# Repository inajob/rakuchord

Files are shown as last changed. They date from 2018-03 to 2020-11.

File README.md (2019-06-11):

# RakuChord - らくこーど

楽にそれっぽい演奏ができる楽器です。

紹介ページ: https://inajob.github.io/rakuchord/

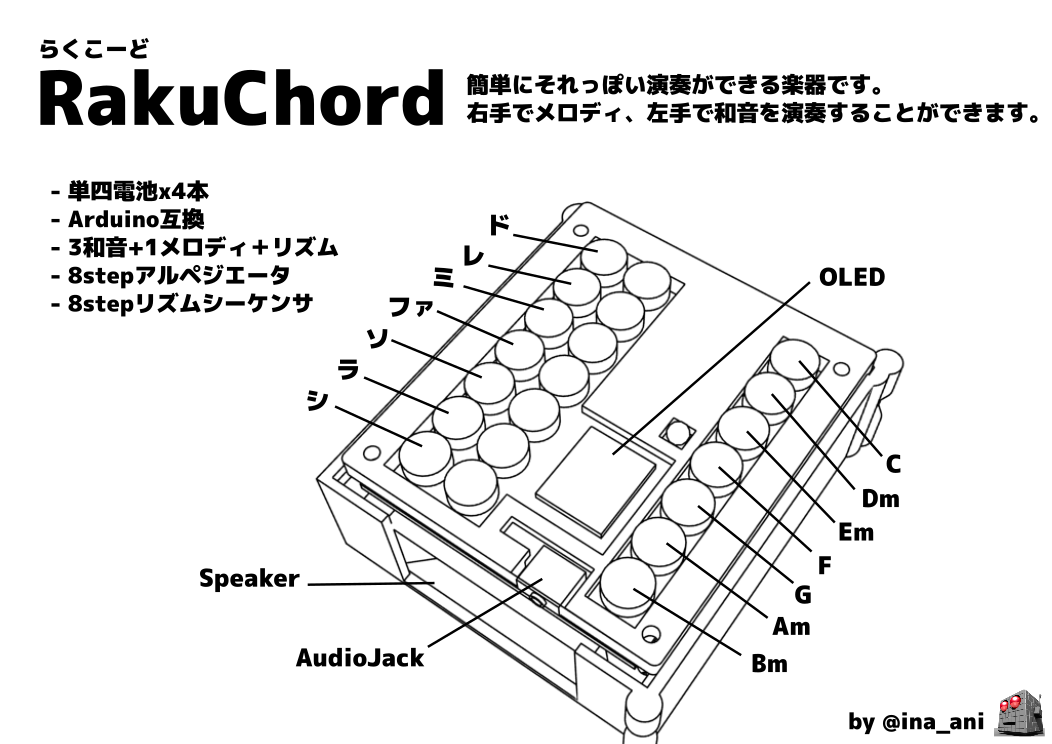
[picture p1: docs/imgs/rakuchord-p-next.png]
RakuChord


# ディレクトリ構成

- docs
  - github pages用ページ
- firmware
  - 本体firmware
- model
  - 筐体データ
- circuit
  - 回路図

# ファームウェアの更新

ビルドには[Platformio](https://platformio.org/)を利用しています。
このリポジトリをCloneしたのちに下記コマンドでファームウェアを更新できます。

```
$ cd firmware
$ platformio run
```

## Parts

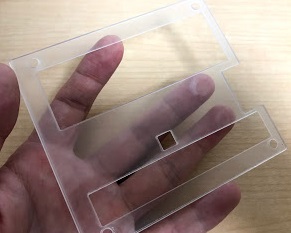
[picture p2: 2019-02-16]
docs/imgs/parts-next/top-panel.jpg

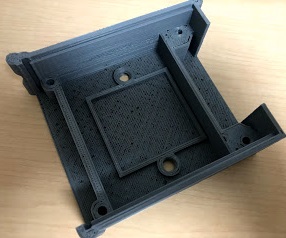
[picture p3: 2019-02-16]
docs/imgs/parts-next/bottom.jpg

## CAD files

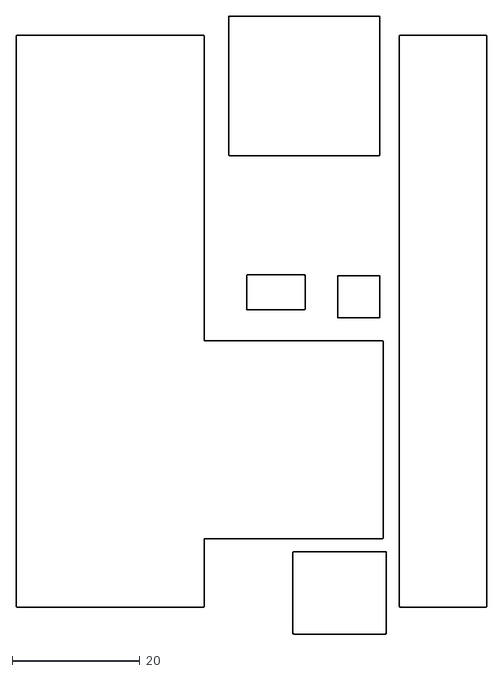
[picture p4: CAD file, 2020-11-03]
model/dxf-1-4/rakuchord-draft-Dwgs_User.dxf
73.7 x 96.7

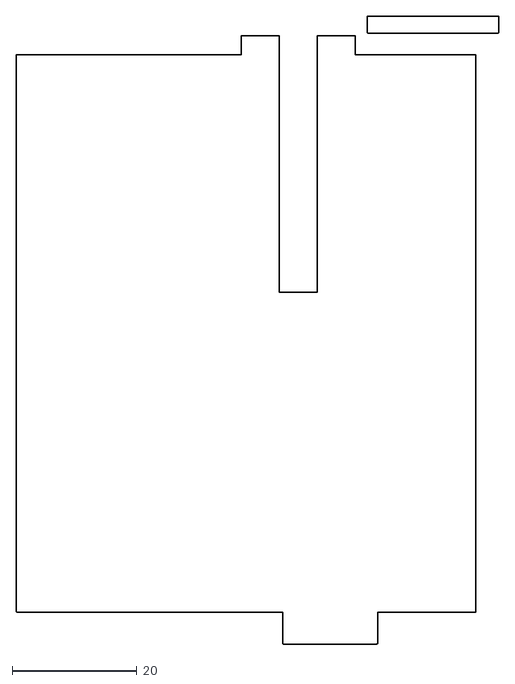
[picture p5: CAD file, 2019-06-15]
model/dxf/rakuchord-draft-Eco1.User.dxf
77.3 x 100.7

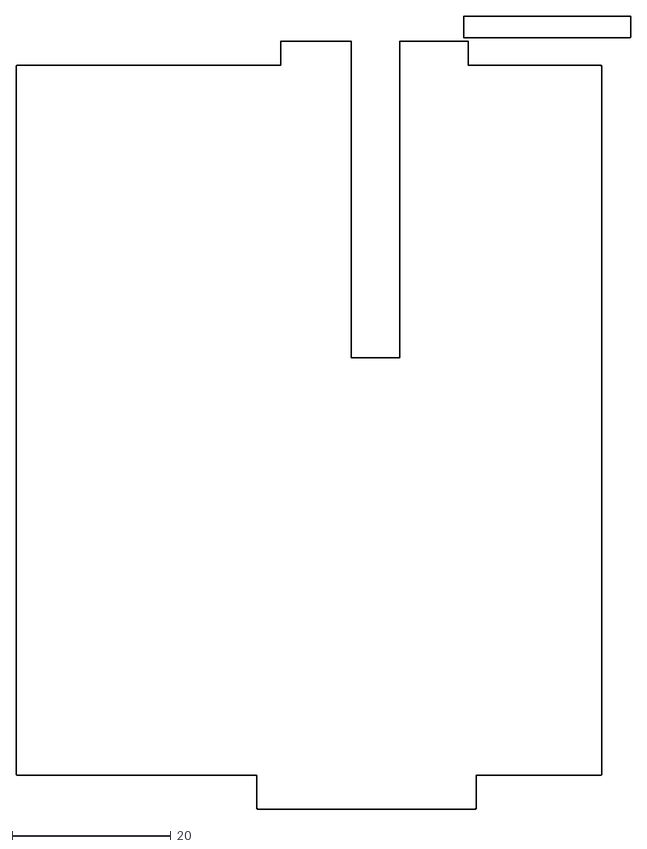
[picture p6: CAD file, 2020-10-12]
model/dxf-1-4/rakuchord-draft-Eco1_User.dxf
77.3 x 99.8

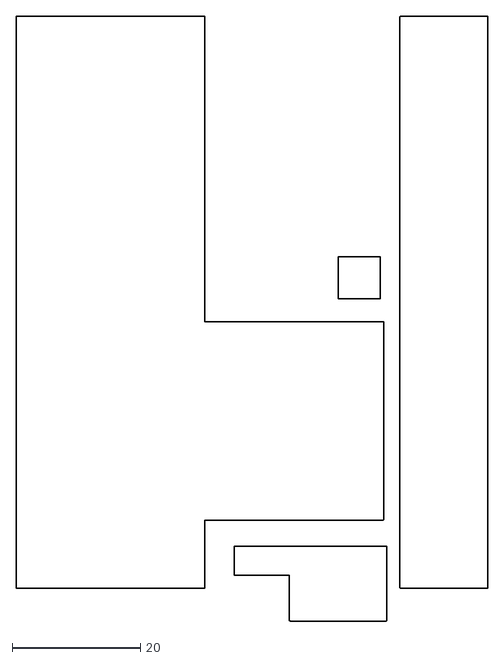
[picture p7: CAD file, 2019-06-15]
model/dxf/rakuchord-draft-Dwgs.User.dxf
73.7 x 94.5

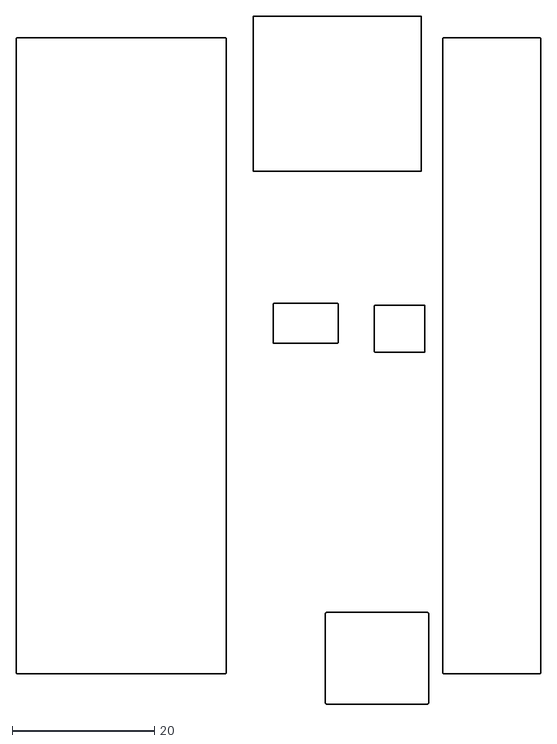
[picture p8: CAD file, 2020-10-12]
model/dxf-1-4/rakuchord-draft-Margin.dxf
73.7 x 96.7

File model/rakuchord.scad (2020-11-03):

include <polyScrewThread_r1.scad>;

//linear_extrude(height = 5, center = true, convexity = 10)
$fn=50;

module screw_hole(){
    translate([92/2 - 5, 92/2-2 + 1,0]) screw_hole_model();
    translate([92/2 - 5, -92/2 + 3,0]) screw_hole_model();

    translate([-92/2 + 5, 92/2-2 + 1,0]) screw_hole_model();
    translate([-92/2 + 5, -92/2 + 3,0]) screw_hole_model();
}
module screw_hole_model(){
    union(){
        cylinder(h = 5, r1 = 3.5, r2 = 3.5, center = false, $fn=6);    
        translate([0,0,5])
          cylinder(h = 3, r1 = 3.5, r2 = 2.5, center = false);
        translate([0,0,0])
          cylinder(h = 200, r1 = 2.5, r2 = 2.5);
    }
}

module base_board(){
      square([92, 100], center = true);
}

module base_board_space(){
    minkowski()
    {
      // base board
      base_board();
      // margin
      circle(1);
    }
}

module hemi_sphere(r){
    difference(){
      sphere(r);
      translate([0,0,-r])cube([r*2,r*2,r*2],center = true);
    }
}

module upper_case_outer(){
    translate([0,0, 6]) rotate([0,180,0]) linear_extrude(6){
        translate([0,3,0])
          offset(2) offset(-2){
            square([93,100+4], center=true);
          }
    }
}

module upper_hole(){
  //square([73, 90], center = true);
  translate([-136,77,0])
    import(file = "dxf/rakuchord-draft-Eco1_User.dxf");
}
module upper_hole2(){
  translate([-136,77,0])
    import(file = "dxf/rakuchord-draft-Dwgs_User.dxf");
}

module key1_space(){
  translate([12+8,100/2 - 1,1]) square([23,3]); // key1
  translate([-6,100/2 - 5,1]) square([25,3]); // key1
}

module cable_hole(){
  translate([-5,-100/2,1]) square([30,5]);
}

module jack_diff(){
    translate([13.5,-40,0]) rotate([90,0,0]) linear_extrude(height=20){
       translate([0,5,0])square([14+2,14], center = true);
       circle(7);
    }
}

*base_board();

// not maintain: case
*union(){
    difference(){
        upper_case_outer(13);
        translate([0,0,-8])linear_extrude(height=11){
          screw_hole(r=4);
          upper_hole();
          *cable_hole();
          translate([-5,-53,1]) square([30,8]);
        }
    }
}

// no use: upper parts of top
*linear_extrude(height=3) difference(){
    translate([0,0, 0]) rotate([0,180,0]){
        translate([0,3,0])
          offset(2) offset(-2){
            square([93,100+4], center=true);
          }
    }
    translate([92/2 - 5, 92/2-2 + 1,0]) circle(2);
    translate([92/2 - 5, -92/2 + 3,0]) circle(2);
    translate([-92/2 + 5, 92/2-2 + 1,0]) circle(2);
    translate([-92/2 + 5, -92/2 + 3,0]) circle(2);
    upper_hole();
}

// no use: lower parts of top
*translate([0,0,3]) linear_extrude(height=3) difference(){
    translate([0,0, 0]) rotate([0,180,0]){
        translate([0,3,0])
          offset(2) offset(-2){
            square([93,100+4], center=true);
          }
    }

    translate([92/2 - 5, 92/2-2 + 1,0]) circle(2);
    translate([92/2 - 5, -92/2 + 3,0]) circle(2);
    translate([-92/2 + 5, 92/2-2 + 1,0]) circle(2);
    translate([-92/2 + 5, -92/2 + 3,0]) circle(2);

    upper_hole2();
}

// top
*translate([0,0,40]) difference(){
    upper_case_outer();
    translate([0,0,0])linear_extrude(height=3){
      upper_hole();
      *cable_hole();
    }
    translate([0,0,-10])linear_extrude(height=50){
      upper_hole2();
    }
    translate([0,0,-30])
      screw_hole();
    translate([0,0,0]) linear_extrude(height=3){
        //base_board_space();
        *difference(){
            offset(1){
                lower_case_outer();
            }
            offset(0){
                lower_case_inner();
            }
        }
    }
    translate([0,0,2])linear_extrude(height=5){
      *key1_space();
    }
    jack_diff();
    // this makes easier for 3D print
    translate([0,0,5.5]) linear_extrude(height = 0.5){
      translate([20,4,0]) square([10,0.5], center = true);
      
      translate([50,45,0]) square([20,0.5], center = true);
      translate([-50,45,0]) square([20,0.5], center = true);
      translate([50,-43,0]) square([20,0.5], center = true);
      translate([-50,-43,0]) square([20,0.5], center = true);
    }
}

module sub_board(){
      translate([0,100/2 + 2,-15]) rotate([90,0,0]) square([93, 30], center = true);
}

module lower_case_outer(){
    hull(){
      translate([93/2 ,100/2 + 2,0]) circle(5, $fn=50);
      translate([-93/2 ,100/2 + 2,0]) circle(5, $fn=50);
    }
    square([92+1+6, 100+10], center = true);
    hull(){
        translate([93/2 -1 ,-100/2,0]) circle(2, $fn=50);
        translate([-93/2 +1 ,-100/2,0]) circle(2, $fn=50);
    }
}
module lower_case_outer_edge(){
  square([92+1, 105], center = true);
}

module lower_case_inner(){
    square([95 - 6, 105], center = true);
    translate([0,52,0]) square([94, 3], center = true);
    translate([0,50,0]) square([93 - 8, 3], center = true);

    translate([0,55,0]) square([93 - 15+10, 5], center = true);
    translate([0,-50,0]) square([57, 5+10], center = true);
}

*sub_board();

module speaker_hold(){
    linear_extrude(height = 20){
        translate([-94/2 + 12,-50 + 5 + 10/2-5,0]) scale(5) {
            translate([-2,-1,0]) square([1, 3.5]);
            mirror([0,1,0]) polygon([[-1,-2.5],[1,-2.5],[1,0],[0,1],[-1,1]]);
            translate([-2,-2,0]) square([1.5,1]);
        }
        
    }
    linear_extrude(height = 15){
        translate([-94/2 + 12,45.5,0]) scale(5) {
            translate([-2,-1,0]){
                square([1, 2]);
                
            }
            translate([-1,0,0]){
                circle(1, $fn=50);
            }
        }
        translate([0,40,0])
          square([49,5]);
    }
}


thread = "none"; //modeled


*translate([0,0,-34]){
    difference(){
        union(){
            linear_extrude(height = 36){
                difference(){
                  lower_case_outer();
                  lower_case_inner();
                }
            }
            difference(){
                union(){
                    linear_extrude(height = 2){
                        lower_case_outer();
                    }
                    linear_extrude(height = 5) translate([33,0,0]) circle(7);
                    linear_extrude(height = 5) translate([-33,0,0]) circle(7);
                }
                hg = 8;  // height
                sth = 4; // step height
                clf = 55; // degrees
                cod = 10; // outer diameter
                crs = 1; // resolution

                //translate([33, 0, 20]) hole_threaded(name="M10", thread = thread);
                //translate([-33, 0, 20]) hole_threaded(name="M10", thread = thread);
                translate([33, 0, 0]) screw_thread(cod,sth,clf,8,crs,-2);
                translate([-33, 0, 0]) screw_thread(cod,sth,clf,8,crs,-2);;
                screw_hole();
            }
            linear_extrude(height = 5){
                difference(){
                    square([50+2+4, 53+2+4], center = true);
                    square([50+1, 53+1], center = true);
                }
            }
            speaker_hold();
            mirror([-1,0,0]) speaker_hold();
            linear_extrude(height=20)translate([0,-32,0])square([96,3],center=true);
            translate([46+2,-51-5,0]){
                cylinder(h = 11, r1 = 4, r2 = 4, $fn = 40);
                translate([0,0,11])cylinder(h = 5, r1 = 4, r2 = 2, $fn = 40);
                
                translate([0,0,16])cylinder(h = 4, r1 = 2, r2 = 2, $fn = 40);
                
                translate([0,0,20])cylinder(h = 5, r1 = 2, r2 = 4, $fn = 40);
                translate([0,0,20 + 5])cylinder(h = 11, r1 = 4, r2 = 4, $fn = 40);
            }
            translate([49,57,0]){
                cylinder(h = 11, r1 = 4, r2 = 4, $fn = 40);
                translate([0,0,11])cylinder(h = 5, r1 = 4, r2 = 2, $fn = 40);
                
                translate([0,0,16])cylinder(h = 4, r1 = 2, r2 = 2, $fn = 40);
                
                translate([0,0,20])cylinder(h = 5, r1 = 2, r2 = 4, $fn = 40);
                translate([0,0,20 + 5])cylinder(h = 11, r1 = 4, r2 = 4, $fn = 40);
            }
        }
        translate([0,0,33]){
            linear_extrude(height = 5){
                lower_case_outer_edge();
            }
        }
        screw_hole();
        // this makes easier for 3D print
        linear_extrude(height = 0.5){
          translate([50,0,0]) square([20,0.5], center = true);
          translate([-50,0,0]) square([20,0.5], center = true);
          translate([50,45,0]) square([20,0.5], center = true);
          translate([-50,45,0]) square([20,0.5], center = true);
          translate([50,-43,0]) square([20,0.5], center = true);
          translate([-50,-43,0]) square([20,0.5], center = true);
        }

    }
}
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

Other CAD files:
model/polyScrewThread_r1.scad

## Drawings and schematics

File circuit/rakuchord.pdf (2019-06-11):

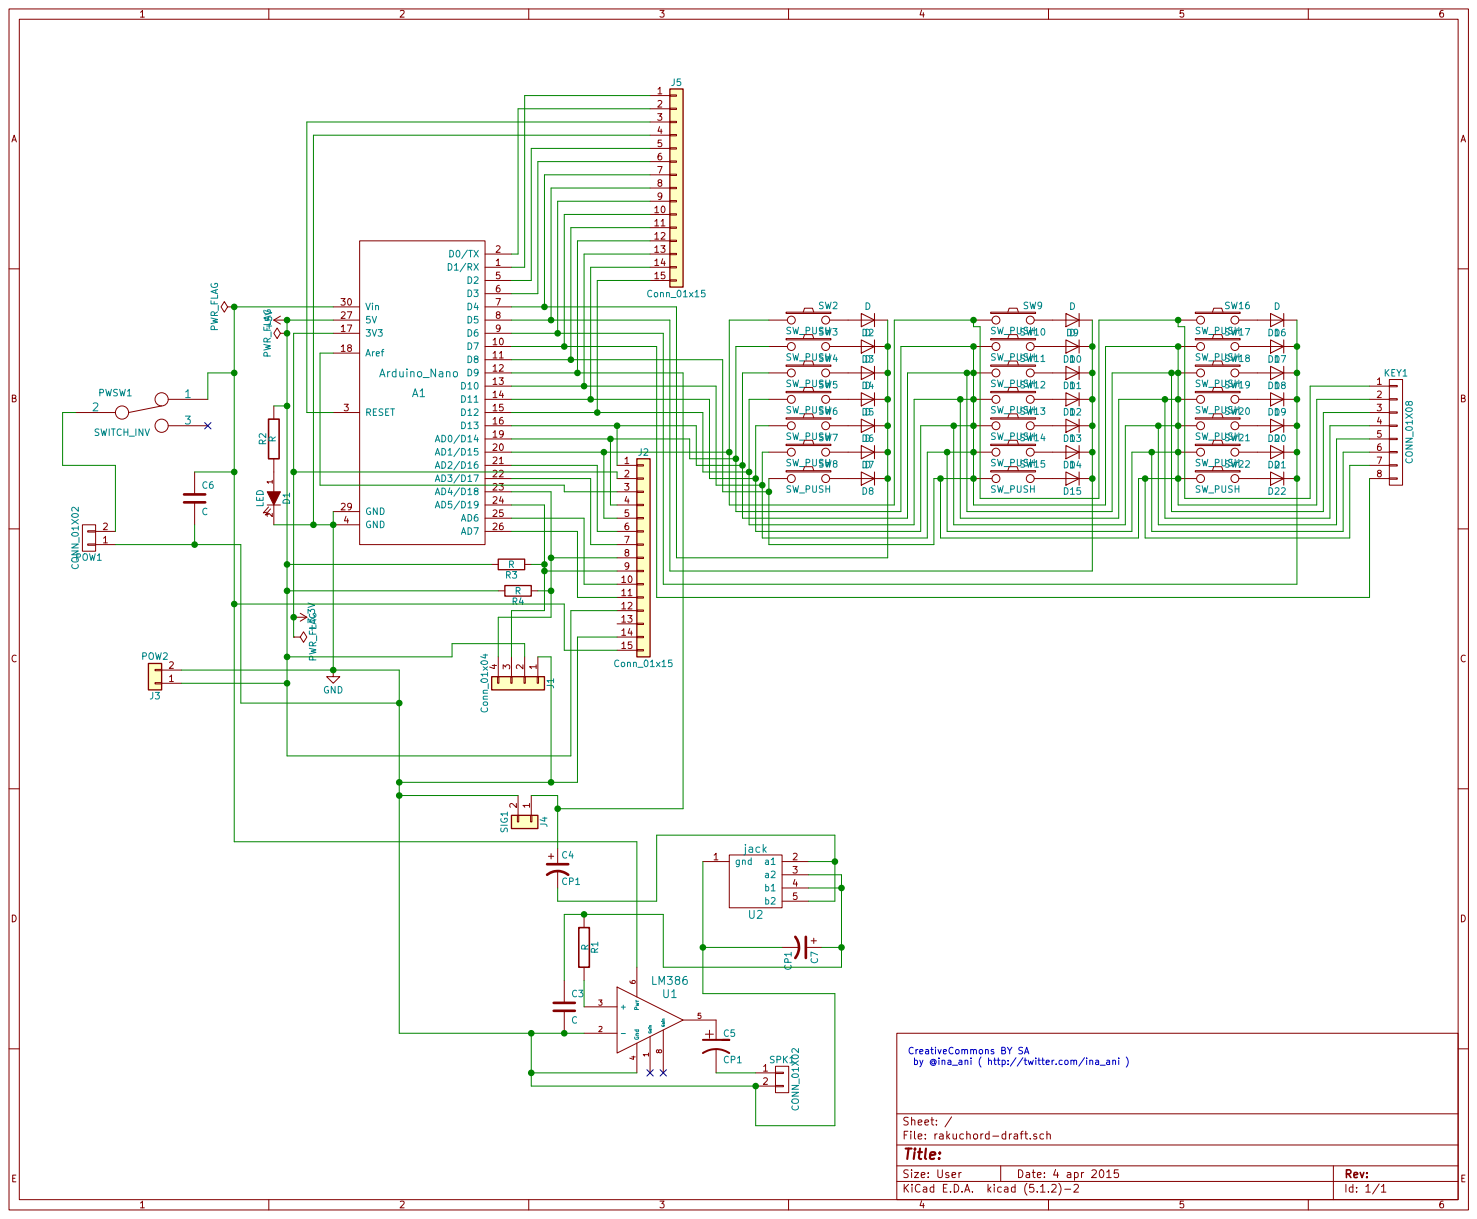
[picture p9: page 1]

CreativeCommons BY SA
by @ina_ani ( http://twitter.com/ina_ani )

Id: 1/1 Title: File: rakuchord-draft.sch Sheet: /

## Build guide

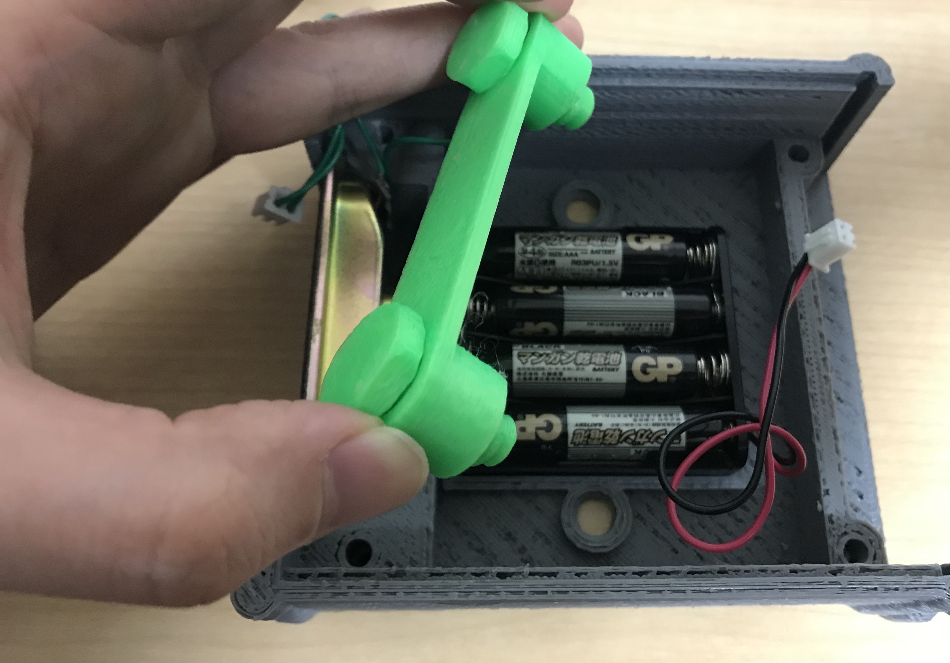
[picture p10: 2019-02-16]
docs/imgs/instruction-out-next/1820-battery.jpg

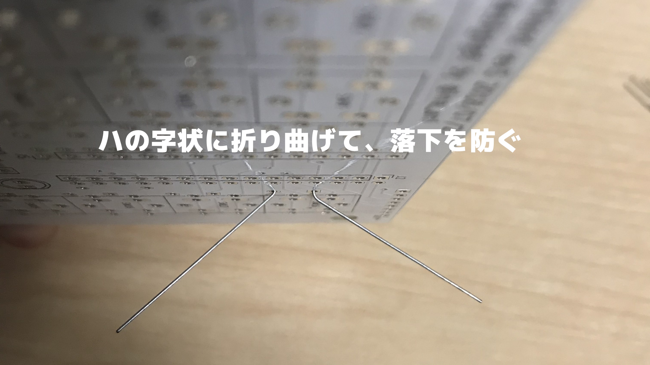
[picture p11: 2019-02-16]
docs/imgs/instruction-out-next/0110-diode-foot.jpg

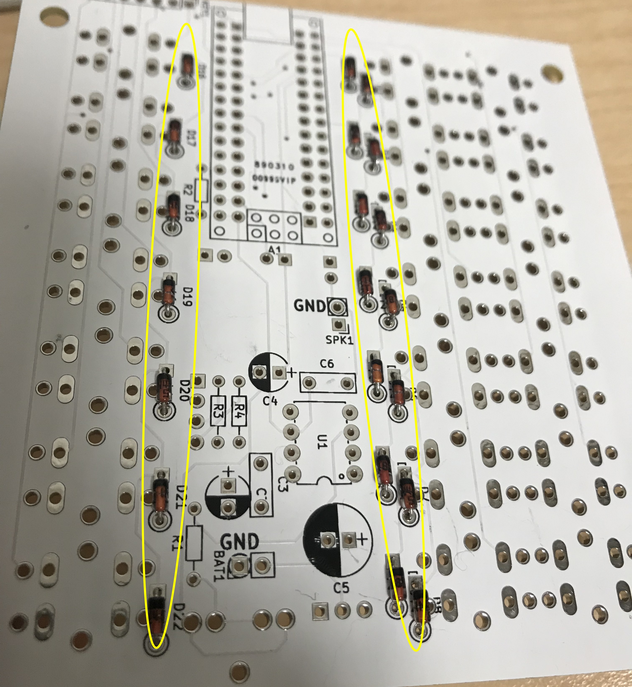
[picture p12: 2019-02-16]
docs/imgs/instruction-out-next/0120-diode-mount.jpg

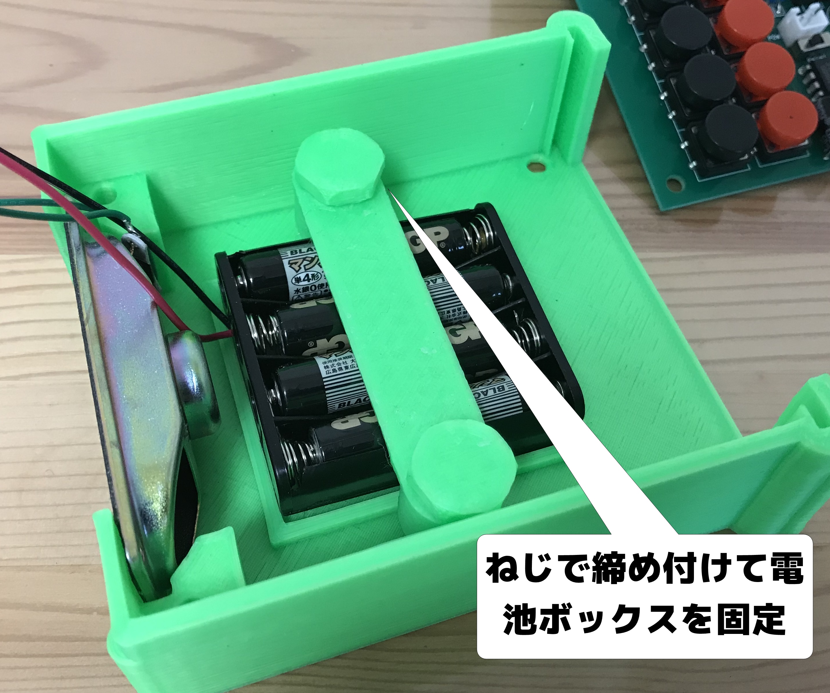
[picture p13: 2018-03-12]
docs/imgs/instruction-out/044-battery-case.jpg

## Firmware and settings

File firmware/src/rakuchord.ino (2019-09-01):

// rakuchord_pencase extend
// fork 2014.11.30
//  pencase: 168 (compatible)
//  nenga: 328 (compatible)

// rakuchord first - 0
// rakuchord rev2

#include <math.h>
#include <SPI.h>
#include <Wire.h>
#include "tones.h"
#include "MultiTunes.h"
#include "font.h"

#define ADDRESS_OLED 0x3C
#define LINE_BUF_LEN 20

static byte trigger[] = {
  0, 0, 0, 0, 0, 0, 0,
  0, 0, 0, 0, 0, 0, 0,
  0, 0, 0, 0, 0, 0, 0,
  0, 0, 0, 0, 0, 0, 0
};

// =========================================-
#define M_PLAY 0
#define M_STEP 1
#define M_SYNTH 2
#define M_MENV 3
#define M_CENV 4
#define M_ALPE 5
byte gmode = M_PLAY;
boolean gsetting = false;

struct Setting {
  char octave;
  char croctave;
  byte waveType;
  byte aseq[8];
  bool galpe;
  unsigned int rSpeed;
  int arSpeed;
  byte mEnvMode;
  byte cEnvMode;
  byte rseq[8];
  bool grythm;
  bool vf;
};

struct Setting preset[4] ={
  { // == simple =====================================
   1, // octave
   1, // croctave
   0, // waveType
   {1, 2, 3, 0, 1, 2, 3, 0}, // aseq
   false, // galpe
   1200, // rSpeed
   0, // arSpeed
   0, // mEnvMode
   0, // cEnvMode
   {  // rseq
     0x3f,
     0x3f,
     0x3f | 0x80,
     0,
     0x3f,
     0x3f,
     0x3f | 0x80,
     0
   },
   false, // grythm
   false, // vf
  },
  { // == pico rythm =====================================
   1, // octave
   0, // croctave
   1, // waveType
   {1, 2, 3, 0, 1, 2, 3, 0}, // aseq
   true, // galpe
   1200, // rSpeed
   0, // arSpeed
   0, // mEnvMode
   0, // cEnvMode
   {  // rseq
     0x3f,
     0x3f,
     0x3f | 0x80,
     0,
     0x3f,
     0x3f,
     0x3f | 0x80,
     0
   },
   true, // grythm
   false, // vf
  },
  { // == loud  =====================================
   1, // octave
   0, // croctave
   0, // waveType
   {1, 2, 3, 0, 1, 2, 3, 0}, // aseq
   false, // galpe
   1200, // rSpeed
   0, // arSpeed
   0, // mEnvMode
   0, // cEnvMode
   {  // rseq
     0x3f,
     0x3f,
     0x3f | 0x80,
     0,
     0x3f,
     0x3f,
     0x3f | 0x80,
     0
   },
   false, // grythm
   true, // vf
  },
  { // == another seq  =====================================
   1, // octave
   0, // croctave
   0, // waveType
   {0, 4, 1, 4, 0, 4, 1, 4}, // aseq
   true, // galpe
   1200, // rSpeed
   0, // arSpeed
   0, // mEnvMode
   0, // cEnvMode
   {  // rseq
     0x3f,
     0x3f,
     0x3f | 0x80,
     0,
     0x3f,
     0x3f,
     0x3f | 0x80,
     0
   },
   true, // grythm
   false, // vf
  },



};

char octave = 1;
char croctave = 1; // 和音相対オクターブ
char shiftTone = 12;
char shiftMagic = 0;
#define M_NONE 0
#define M_MAJOR 1
#define M_MINOR 2
#define M_SUS4 3
byte shiftMode = M_NONE;
byte glideMode = 0;
byte waveType = 0;

byte apos = 0;
byte aseq[]= {1, 2, 3, 0, 1, 2, 3, 0};
boolean galpe = false;

unsigned int rythmCount = 0;
unsigned int alpeCount = 0;

int aV[] = {0,0,0,0};
byte toneCount = 0;

#define DSPPED 1200
unsigned int rSpeed = DSPPED;
int arSpeed = 0; // alpe speed
byte mEnvMode = 0;
byte cEnvMode = 0;

byte rpos = 1;
byte rseq[]= {
  0x3f,
  0x3f,
  0x3f | 0x80,
  0,
  0x3f,
  0x3f,
  0x3f | 0x80,
  0
  };
boolean grythm = false;

void loadSetting(struct Setting *setting){
  octave = setting->octave;
  croctave = setting->croctave;
  waveType = setting->waveType;
  memcpy(aseq, setting->aseq, 8);
  galpe = setting->galpe;
  rSpeed = setting->rSpeed;
  arSpeed = setting->arSpeed;
  mEnvMode = setting->mEnvMode;
  cEnvMode = setting->cEnvMode;
  memcpy(rseq, setting->rseq, 8);
  grythm = setting->grythm;
  vf = setting->vf;

  mkWave(waveType);
}

inline int getTone(byte no){
  return  (tones[shiftMagic + magic[no] + shiftTone]) << (octave);
}

void setTone(byte no, byte p){
  vol[0] = 14;
  d[0] = getTone(no) + ((glideMode == 1)?(p-255):0);
  if(vf){ // detune
    vol[4] = 8;
    d[4] = getTone(no) + (getTone(no) >> 6);
  }
}
#define LOW_VOL 6
#define MID_VOL 12
#define ALPE_VOL 14

int getMiddleMajorTone(byte no){
  switch(shiftMode){
    case M_NONE: return getTone(no + 2);
    case M_MAJOR:return getTone(no + 2);
    case M_MINOR:return (tones[shiftMagic + magic[no+2] - 1 + shiftTone]) << octave;
    case M_SUS4: return (tones[shiftMagic + magic[no+2] + 1 + shiftTone]) << octave;
  }
  return 0; //error
}

int getMiddleMinorTone(byte no){
  switch(shiftMode){
    case M_NONE: return getTone(no + 2);
    case M_MINOR:return getTone(no + 2);
    case M_MAJOR:return (tones[shiftMagic + magic[no+2] + 1 + shiftTone]) << octave;
    case M_SUS4: return (tones[shiftMagic + magic[no+2] + 2 + shiftTone]) << octave;
  }
  return 0; //error
}

int shift(int n, int s){
  if(s > 0)return n >> s;
  return n << (-s);
}

void setChord(byte no){
  char buf[32];
  // Initializing to 0 would make the firmware believe C was playing.
  static byte pre = 0xff;
  static byte preAdd = M_NONE;
  if(pre != no || preAdd != shiftMode){
    pre = no;
    preAdd = shiftMode;
    sprintf(buf, "chord %d", no);
    TIMSK1 = 0;
    lcdDraw(no, shiftMode);
    TIMSK1 = 1<<TOIE1;
  }

  if(galpe){
    byte tmp = magic[no + 2] - magic[no];
    unsigned int middle;
    switch(tmp){
        case 4: middle = getMiddleMajorTone(no);break;
        case 3: middle = getMiddleMinorTone(no);break;
    }
    unsigned int alpeTones[] = {getTone(no) >> 1, getTone(no), middle, getTone(no + 4), 0};

    d[1] = shift(alpeTones[aseq[apos]],croctave);
    vol[1] = ALPE_VOL;

  }else{
    // not alpe mode
    vol[1] = LOW_VOL;
    d[1] = shift(getTone(no),croctave);

    vol[2] = MID_VOL;
    byte tmp = magic[no + 2] - magic[no];
    switch(tmp){
      case 4: d[2] = shift(getMiddleMajorTone(no),croctave); break;
      case 3: d[2] = shift(getMiddleMinorTone(no),croctave); break;
    }

    vol[3] = LOW_VOL;
    d[3] = shift(getTone(no + 4),croctave);
  }
}
void setShift(byte no){
  switch(no){
    case 6:
      break;
    case 3: shiftTone -=1; drawDisplay();break;
    case 4: shiftTone = 12; drawDisplay();break;
    case 5: shiftTone +=1; drawDisplay();break;
    //case 3: shiftTone -=1;break;
    //case 4: shiftTone = 12;break;
    //case 5: glideMode = 1;break;
    case 0: shiftMode = M_SUS4;break;
    case 1: shiftMode = M_MAJOR;break;
    case 2: shiftMode = M_MINOR;break;
  }
}
void setSynthShift(byte no){
  switch(no){
    case 6:
      break;
    case 0: croctave = -3;break;
    case 1: croctave = -2;break;
    case 2: croctave = -1;break;
    case 3: croctave = 0;break;
    case 4: croctave = 1;break;
    case 5: croctave = 2;break;
  }
  drawDisplay();
}

void setStepShift(byte no){
  switch(no){
    case 6:
      break;
    case 0: rSpeed -=64;break;
    case 1: rSpeed = DSPPED;break;
    case 2: rSpeed +=64;break;
  }
}

void setAlpeShift(byte no){
  switch(no){
    case 6:
      return;
    case 0: arSpeed = 2; break;
    case 1: arSpeed = 1; break;
    case 2: arSpeed = 0; break;
    case 3: arSpeed = -1; break;
    case 4: arSpeed = -2; break;
    case 5: arSpeed = -3; break;
  }

  apos = 0;
  rpos = 1;

  noInterrupts();
  rythmCount = 0;
  alpeCount = 0;
  interrupts();
}

void setStep(byte n){
  switch(rseq[n]){
    case 0:  rseq[n] = 0xf; break;

    case 0xf:  rseq[n] = 0x1f; break;
    case 0x1f:  rseq[n] = 0x3f; break;
    case 0x3f:  rseq[n] = 0xf | 0x80; break;

    case 0xf | 0x80:  rseq[n] = 0x1f | 0x80; break;
    case 0x1f | 0x80:  rseq[n] = 0x3f | 0x80; break;
    case 0x3f | 0x80:  rseq[n] = 0x00; break;
  }
}
void clearStep(){
  for(byte i = 0; i < 8; i ++){
    rseq[i] = 0;
  }
}

void setAStep(byte n){
  aseq[n]++;
  if(aseq[n] > 4){
    aseq[n] = 0;
  }
}
void clearAStep(){
  for(byte i = 0; i < 8; i ++){
    aseq[i] = 4;
  }
}

void drawText(char* buf, byte y){
  Wire.beginTransmission(ADDRESS_OLED);
  Wire.write(0b10000000); //control byte, Co bit = 1, D/C# = 0 (command)
  Wire.write(0xB0 + y); //set page start address(B0～B7)
  Wire.write(0b00000000); //control byte, Co bit = 0, D/C# = 0 (command)
  Wire.write(0x21); //set Column Address
  Wire.write(0); //Column Start Address(0～127)
  Wire.write(127); //Column Stop Address
  Wire.endTransmission();

  bool inverted = false;
  while(*buf != 0){
    switch(*buf){
      case '\a': //invert
        inverted = true;
        buf++;
        break;
      case '\b': //invert
        inverted = false;
        buf++;
        break;
    }
    Wire.beginTransmission(ADDRESS_OLED);
    Wire.write(0b01000000);
    Wire.write(inverted?0xfe:0x00);
    for(int i = 0; i < 3; i ++){
      if(inverted){
        Wire.write(0xfe&~pgm_read_byte_near(&(font[*buf-' '][i])));
      }else{
        Wire.write(pgm_read_byte_near(&(font[*buf-' '][i])));
      }
    }
    Wire.write(inverted?0xfe:0x00);
    Wire.endTransmission();
    buf++;
  }
}

char getMEnvModeChar(){
  switch(mEnvMode){
    case 0: return 'N';
    case 3: return 'F';
  }
}
char getCEnvModeChar(){
  switch(cEnvMode){
    case 0: return 'N';
    case 3: return 'F';
  }
}

void drawDisplay(){
  drawText("=RAKU CHORD=",0);
  char buf[LINE_BUF_LEN];
  char tmp[LINE_BUF_LEN];
 
  // line 2
  switch(waveType){
    case 0:strncpy(tmp, "SAW", 20);break;
    case 1:strncpy(tmp, "SQU", 20);break;
    case 2:strncpy(tmp, "SIN", 20);break;
  }
  sprintf(buf, "\a%3s\b \a%c\b S\a%02d\bO\a%02d", tmp, vf?'D':'*', shiftTone, croctave);
  drawText(buf, 2);

  // line 3, 4 :rythm
  drawRythm();
  if(grythm){
    strncpy(tmp, " \aON\b", LINE_BUF_LEN);
  }else{
    strncpy(tmp, "OFF", LINE_BUF_LEN);
  }
  sprintf(buf, " %s \a%04d", tmp, rSpeed);
  drawText(buf, 4);

  // line 5, 6 :alpe
  drawAlpe();
  if(galpe){
    strncpy(tmp, " \aON\b", LINE_BUF_LEN);
  }else{
    strncpy(tmp, "OFF", LINE_BUF_LEN);
  }
  sprintf(buf, " %s SP:\a%02d", tmp, arSpeed);
  drawText(buf, 6);


  sprintf(buf, "(M:\a%c\b, C:\a%c\b)", getMEnvModeChar(), getCEnvModeChar());
  drawText(buf, 7);
  
  // line7
  switch(gmode){
    case M_PLAY: 
      drawText("\a>> PLAY      ",1);
      break;
    case M_STEP: 
      drawText("\a>> STEP      ",1);
      break;
    case M_SYNTH:
      drawText("\a>> SYNTH     ",1);
      break;
    case M_MENV: 
      drawText("\a>> MELODY ENV",1);
      break;
    case M_CENV: 
      drawText("\a>> CHORD ENV ",1);
      break;
    case M_ALPE: 
      drawText("\a>> ALPE      ",1);
      break;
  }
}

void drawRythm(){
  char buf[LINE_BUF_LEN];
  buf[0] = '\a';
  buf[1] = 'R';
  buf[2] = '\b';
  buf[3] = ' ';
  buf[4] = ' ';
  for(byte i = 0; i < 8; i ++){
    switch(rseq[i]){
      case 0x00:      buf[i + 5]='_';break;

      case 0x0f:      buf[i + 5]='A';break;
      case 0x1f:      buf[i + 5]='B';break;
      case 0x3f:      buf[i + 5]='C';break;

      case 0x8f|0x80: buf[i + 5]='1';break;
      case 0x9f|0x80: buf[i + 5]='2';break;
      case 0xbf|0x80: buf[i + 5]='3';break;
    }
  }
  buf[13] = ' ';
  buf[14] = 0;
  drawText(buf, 3);
}

void drawAlpe(){
  char buf[LINE_BUF_LEN];
  buf[0] = '\a';
  buf[1] = 'A';
  buf[2] = '\b';
  buf[3] = ' ';
  buf[4] = ' ';
  for(byte i = 0; i < 8; i ++){
    switch(aseq[i]){
      case 0: buf[i + 5]='0';break;
      case 1: buf[i + 5]='1';break;
      case 2: buf[i + 5]='2';break;
      case 3: buf[i + 5]='3';break;
      case 4: buf[i + 5]='_';break;
    }
  }
  buf[13] = ' ';
  buf[14] = 0;
  drawText(buf, 5);
}

#define SAMPLE 64

void mkWave(byte type){
  waveType = type;
  for (byte i = 0; i < 16; i++) {
    byte sample;

    for (byte j = 0; j < SAMPLE; j++) {
      switch (type) {
        case 0:
          sample = i*j/(SAMPLE); // i : vol, j : t
          break;
        case 1:
          sample = 2 * i * ((j & (SAMPLE>>1))?8:0)/(16+8);  // 8 : 0B100
          break;
        case 2:
          sample = i*((sin(j*2*3.14/SAMPLE)+1)/2 * 8)/16;
          break;
      }
      if (!(i & 1))
        wave[i/2][j] = sample & 0xf;
      else
        wave[i/2][j] |= sample << 4;
    }
  }
}

void triggerOn(byte n){
  if(trigger[n] == 0){
    // event on
    if(n == 27){
      gsetting = true;
    }
  }
  if(!gsetting){
    switch(gmode){
      case M_PLAY:
        if(trigger[n] == 0){
          // event on
        }
        if(n < 14){
          setTone(n, trigger[n]);
        }else if(n < 21){
          setChord(n - 14);
        }else{
          if(n < 28){
            if(trigger[n] == 0){
              setShift(n - 21);
            }
          }
        }
        break;
      case M_STEP:
        if(trigger[n] == 0){
          // event on
          if(n == 0){
            clearStep();
          }
          if(n < 14){
            if(n >= 6){
              setStep(n - 6);
            }
          }
          if(n < 28){
            setStepShift(n - 21);
          }
          drawDisplay();
        }
        if(14 <= n && n < 21){
          setChord(n - 14);
        }
        break;
      case M_SYNTH:
        if(trigger[n] == 0){
          switch(n){
            case 0: mkWave(0);break;
            case 1: mkWave(1);break;
            case 2: mkWave(2);break;
          }
          drawDisplay();
        }
        if(n >= 7 && n < 14){
          setTone(n, trigger[n]);
        }else if(n >=7 && n < 21){
          setChord(n - 14);
        }else{
          if(n < 28){
            if(trigger[n] == 0){
              setSynthShift(n - 21);
            }
          }
        }
        break;
      case M_MENV:
        if(trigger[n] == 0){
          switch(n){
            case 0: mEnvMode = 0;break;
            //case 1: mEnvMode = 1;break;
            //case 2: mEnvMode = 2;break;
            case 1: mEnvMode = 3;break;
          }
          drawDisplay();
        }
        if(n >= 7 && n < 14){
          setTone(n, trigger[n]);
        }else if(14 <= n && n < 21){
          setChord(n - 14);
        }
        break;
      case M_CENV:
        if(trigger[n] == 0){
          switch(n){
            case 0: cEnvMode = 0;break;
            //case 1: cEnvMode = 1;break;
            //case 2: cEnvMode = 2;break;
            case 1: cEnvMode = 3;break;
          }
          drawDisplay();
        }
        if(n >= 7 && n < 14){
          setTone(n, trigger[n]);
        }else if(n >=14 && n < 21){
          setChord(n - 14);
        }
        break;
      case M_ALPE:
        if(trigger[n] == 0){
          // event on
          if(n == 0){
            clearAStep();
          }
          if(n < 14){
            if(n >= 6){
              setAStep(n - 6);
            }
          }
          if(n < 28){
            setAlpeShift(n - 21);
          }
          drawDisplay();
        }
        if(14 <= n && n < 21){
          setChord(n - 14);
        }
        break;
    }
  }else{ // gsetting
    if(trigger[n] == 0){
      switch(n){
        case 0: galpe = false;  break;
        case 1: galpe = true;   break;
        case 2: grythm = false; break;
        case 3: grythm = true;  break;
        case 4: vf = 0;         break;
        case 5: vf = 1;         break;

        case 7: loadSetting(&preset[0]);break;
        case 8: loadSetting(&preset[1]);break;
        case 9: loadSetting(&preset[2]);break;
        case 10: loadSetting(&preset[3]);break;

        case 14:gmode = M_PLAY; break;
        case 15:gmode = M_STEP; break;
        case 16:gmode = M_SYNTH;break;
        case 17:gmode = M_MENV; break;
        case 18:gmode = M_CENV; break;
        case 19:gmode = M_ALPE; break;
      }
      drawDisplay();
    }
  }
  if(trigger[n] < 255){
    trigger[n] ++;
  }
}
void triggerOff(byte n){
  byte count = 0;
  if(trigger[n] != 0){
    trigger[n] = 0;
    if(n >= 21){
      shiftMode = M_NONE;
      glideMode = 0;
    }
    if(n == 27){
      gsetting = false;
    }
  }
}
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
void loop(){

  updateRythm();
  updateAlpe();

  if(rcount == 0){
    // rethm decay
    if(nf != 0){
      nf = (nf >> 1);
    }
    if(nf2 != 0){
      nf2 = (nf2 >> 1);
    }
  }

  if(count == 0){
    uint8_t fast_decay;
    uint8_t fast_decay_rate;

    // melody decay
    getDecayParams(mEnvMode, &fast_decay, &fast_decay_rate);
    if (vol[0] > fast_decay) vol[0] -= fast_decay_rate;
    else if (vol[0] > 0) vol[0]--;

    // chord decay
    getDecayParams(cEnvMode, &fast_decay, &fast_decay_rate);
    for (int i = 1; i < 5; i++) {
      if (vol[i] > fast_decay) vol[i] -= fast_decay_rate;
      else if (vol[i] > 0) vol[i]--;
    }
  }

  if(bcount == 0){
    // button scan loop
    bscan++;
    if(bscan == 8){
      bscan = 0;
    }
    switch(bscan){
      case 0:
        pinMode(4, INPUT);
        digitalWrite(4, HIGH);
        pinMode(5, INPUT);
        digitalWrite(5, HIGH);
        pinMode(6, INPUT);
        digitalWrite(6, HIGH);
        pinMode(7, OUTPUT);
        digitalWrite(7, LOW);
        break;
      case 1:
        pinMode(4, INPUT);
        digitalWrite(4, HIGH);
        pinMode(5, OUTPUT);
        digitalWrite(5, LOW);
        pinMode(6, INPUT);
        digitalWrite(6, HIGH);
        pinMode(7, INPUT);
        digitalWrite(7, HIGH);
      break;
      case 2:
        pinMode(4, INPUT);
        digitalWrite(4, HIGH);
        pinMode(5, INPUT);
        digitalWrite(5, HIGH);
        pinMode(6, OUTPUT);
        digitalWrite(6, LOW);
        pinMode(7, INPUT);
        digitalWrite(7, HIGH);
      break;
      case 3:
        pinMode(4, OUTPUT);
        digitalWrite(4, LOW);
        pinMode(5, INPUT);
        digitalWrite(5, HIGH);
        pinMode(6, INPUT);
        digitalWrite(6, HIGH);
        pinMode(7, INPUT);
        digitalWrite(7, HIGH);
      break;

    }
  }

  // button read
  boolean b1 = digitalRead(15);
  boolean b2 = digitalRead(14);
  boolean b3 = digitalRead(13);
  boolean b4 = digitalRead(12);
  boolean b5 = digitalRead(11);
  boolean b6 = digitalRead(10);
  boolean b7 = digitalRead(8);

  boolean pushed = false;

  switch(bscan){
    case 0:
      if(!b1){triggerOn(21);}else{triggerOff(21);}
      if(!b2){triggerOn(22);}else{triggerOff(22);}
      if(!b3){triggerOn(23);}else{triggerOff(23);}
      if(!b4){triggerOn(24);}else{triggerOff(24);}
      if(!b5){triggerOn(25);}else{triggerOff(25);}
      if(!b6){triggerOn(26);}else{triggerOff(26);}
      if(!b7){triggerOn(27);}else{triggerOff(27);}
    break;
    case 3:
      if(!b1){triggerOn(0);}else{triggerOff(0);}
      if(!b2){triggerOn(1);}else{triggerOff(1);}
      if(!b3){triggerOn(2);}else{triggerOff(2);}
      if(!b4){triggerOn(3);}else{triggerOff(3);}
      if(!b5){triggerOn(4);}else{triggerOff(4);}
      if(!b6){triggerOn(5);}else{triggerOff(5);}
      if(!b7){triggerOn(6);}else{triggerOff(6);}
    break;
    case 1:
      if(!b1){triggerOn(7);}else{triggerOff(7);}
      if(!b2){triggerOn(8);}else{triggerOff(8);}
      if(!b3){triggerOn(9);}else{triggerOff(9);}
      if(!b4){triggerOn(10);}else{triggerOff(10);}
      if(!b5){triggerOn(11);}else{triggerOff(11);}
      if(!b6){triggerOn(12);}else{triggerOff(12);}
      if(!b7){triggerOn(13);}else{triggerOff(13);}
    break;
    case 2:
      if(!b1){triggerOn(14);pushed = true;}else{triggerOff(14);}
      if(!b2 && pushed == false){triggerOn(15);pushed = true;}else{triggerOff(15);}
      if(!b3 && pushed == false){triggerOn(16);pushed = true;}else{triggerOff(16);}
      if(!b4 && pushed == false){triggerOn(17);pushed = true;}else{triggerOff(17);}
      if(!b5 && pushed == false){triggerOn(18);pushed = true;}else{triggerOff(18);}
      if(!b6 && pushed == false){triggerOn(19);pushed = true;}else{triggerOff(19);}
      if(!b7 && pushed == false){triggerOn(20);pushed = true;}else{triggerOff(20);}
    break;
  }

  // counter management
  rcount = (rcount + 1) & 0x7f;
  bcount = (bcount + 1) & 0xf;
  count = (count + 1) & 0x1ff;
}

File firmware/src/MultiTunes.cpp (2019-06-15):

#include <Arduino.h>
#include "MultiTunes.h"

volatile unsigned int d[5] = { 0 }; // default value( for debug)
static unsigned int dn[5] = { 0 };// work variable
volatile unsigned char vol[5] = { 0 }; // volume par channel
volatile byte nf;
volatile byte nf2;
int noise;
int noise2;

volatile byte vf;

byte wave[8][64];


const unsigned int timerLoadValue = 220;
//volatile unsigned int lfo = 0;

volatile byte nv = 5;

extern unsigned int rythmCount;
extern unsigned int alpeCount;

void soundSetup(){
  //mkWave(0);

  pinMode(9,OUTPUT);
  // 3-pwm ,pwm
  TCCR1A = _BV(COM1A1) | _BV(WGM10);
  // clk/1 prescale
  TCCR1B = /*_BV(WGM12) |*/ _BV(CS10); //1  		31250
  //TCCR2B = _BV(CS21); //8 	 	3906.25
  //1<<CS22 | 0<<CS21 | 1<<CS20; // clk/128 prescale
  //TCCR2B = TCCR2B & 0b11100000 | 0b00001; // pwm: 31250Hz
  TIMSK1 = 1<<TOIE1; // Timer/Counter2 Overflow Interrupt Enable
  OCR1A = 80; // for debug
  TCNT1 = timerLoadValue;
}

// sample 16 -> 12
// sample 32 -> 11
// sample 64 -> 10
ISR(TIMER1_OVF_vect) {    // Timer/Counter1 Overflow
  static byte realcount = 0;
  static byte timeCount = 0;
  constexpr byte interruptsPerTick = 8;

  TCNT2 = timerLoadValue; // Reset the timer
  dn[0] = dn[0] + d[0];/* + vf * ((*(wave[15] + (lfo >> 10))) << 2);*/
  dn[1] = dn[1] + d[1];
  dn[2] = dn[2] + d[2];
  dn[3] = dn[3] + d[3];
  dn[4] = dn[4] + d[4];

  if((realcount & 0x3f) == 0x3f)noise = (noise>>1) + ((bitRead(noise, 13) xor bitRead(noise, 3) xor 1) << 15);
  noise2 = 2100005341  * noise2 + 1651869;
  realcount ++;
  // wave table (slow)
  //lfo+=lfop;

  unsigned char s[5];
  unsigned char v, sample;
#define GET_WAVE_SAMPLE(i)                           \
    (v = vol[i],                                     \
     (v != 0) ? \
       sample = wave[v / 2][dn[i] >> 10],              \
       ((v & 1) ? sample >> 4 : sample & 0xf)    \
     : 0)

  s[0] = GET_WAVE_SAMPLE(0);
  s[1] = GET_WAVE_SAMPLE(1);
  s[2] = GET_WAVE_SAMPLE(2);
  s[3] = GET_WAVE_SAMPLE(3);
  s[4] = GET_WAVE_SAMPLE(4);

  const unsigned int level =
          s[0] + s[1] + s[2] + s[3] + s[4] +
          ((noise) & nf) + ((noise2>>8) &nf2);
  OCR1A = level;

  // Update time counters
  if (++timeCount == interruptsPerTick) {
    rythmCount++;
    alpeCount++;
    timeCount = 0;
  }
}

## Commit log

2018-03-21 add BOM
2018-07-01 add use case
2018-07-26 add annotation for capaciter
2018-08-19 add model
    [polyScrewThread_r1.scad, rakuchord.scad]
2018-08-19 add circuit
2019-03-03 add switch pin back instruction
2019-03-09 fix number if diode
2019-03-11 describe caution about soldering of diode
2019-03-13 2019/03 edition (#6)
    update for 2019/03 edition
    [rakuchord.scad]
2019-03-14 fix invlid LED polarity
2019-06-09 firmware: allow compilation with arduino-builder
    Fix a few includes and add a rudimentary Makefile to allow building the
    firmware with arduino-builder. Also add a flash command using avrdude.
    [MultiTunes.cpp, rakuchord.ino]
2019-06-09 firmware: fix display of first chord if C
    The variable holding the current chord was initialized to 0, which is
    the value for C. As a result, if we play the C chord right after
    powering on, the chord won't be displayed on the LCD.
    Fix this by setting the chord variable to 0xff, which guarantees it will
    be updated no matter which chord we play.
    [rakuchord.ino]
2019-06-09 firmware: fix display bug when setting chord decay
    When setting the chord decay (setting + chord G), an incorrect range
    check triggers a chord played at an invalid frequency, resulting in
    corruption on the screen. Fix this by restricting the range of keys that
    trigger a chord to the proper range.
    [rakuchord.ino]
2019-06-09 firmware: perform sound setup last
    Perform the sound setup when everything else is initialized, to avoid
    "click" sounds during startup.
    [rakuchord.ino]
2019-06-09 firmware: restrict dn and level's scopes and initialization
    Make sure these variables are only visible where they need to be. Also
    improve their initialization and fix some indentation issues.
    [MultiTunes.cpp]
2019-06-09 firmware: move logo to .text
    This is not currently used, but move the logo data to .text in order to
    save RAM if it is re-enabled.
2019-06-09 firmware: improve wave storage
    Wave samples are in the range [0x0,0xf], but were stored in a full byte.
    Improve storage by storing two levels of volume per byte. Even volume
    numbers are stored in the 4 LSBs or a byte, while odd volume numbers are
    in the 4 MSBs. This allows us to reduce the amount of memory required to
    store the wave samples by half.
    Before: 1712 bytes (83%) of dynamic memory used.
    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
2019-06-11 update 2019/03 circuit
2019-06-15 firmware: fix typo
    "SAW" really meant to be "SIN" here.
    [rakuchord.ino]
2019-06-15 firmware: make realcount static local
    This global variable is never accessed outside of the interrupt handler,
    so there is no reason to make it volatile and visible outside of that
    function.
2019-06-15 firmware: use real time for rythm/arpeggio
    The counters for rythm and arpeggio were updated in the main loop.
    However since that loop has a variable execution time, the rythm could
    go slower or faster depending on the load. This was especially
    noticeable when playing chords and notes at the same time.
    This patch updates the time-sensitive counters in the timer interrupt
    handler, which we know will be called with absolute regularity. It also
    refactors the code a bit so that rythm and arpeggio updates now have
    their own functions. To avoid race conditions between the main loop and
    the interrupt timer, interrupts are temporarily disabled when accessing
    the shared counter variables.
    [MultiTunes.cpp, rakuchord.ino]
2019-06-15 firmware: optimize mixing of chords/notes
    If a channel's volume is zero, we can just skip it in the mixing routine
    and same some CPU time. It was not desirable to do this before because
    the rythm/arpeggio were very dependent on the global speed of the
    program and doing so would increase the variation in rythm. But now that
    rythm is updated according to real time we can apply this optimization.
    [MultiTunes.cpp]
2019-06-15 add missing dxf files
    [rakuchord-draft-Dwgs.User.dxf, rakuchord-draft-Eco1.User.dxf]
2019-06-15 fix model for easy 3d print
    [rakuchord.scad]
2019-09-16 add display description
    [rakuchord.scad]
2020-09-03 add 1-4 frontpanel
    [rakuchord-draft-Dwgs_User.dxf, rakuchord-draft-Eco1_User.dxf, rakuchord-draft-Margin.dxf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]
2020-11-03 update images
    [rakuchord-draft-Dwgs_User.dxf, rakuchord.scad]
